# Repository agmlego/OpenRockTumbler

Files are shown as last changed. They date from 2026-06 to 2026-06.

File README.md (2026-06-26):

OpenRockTumbler
---------------

This project aims to be a drop-in replacement controller for common rock tumblers such as the KoolStone C1 Pro.

# Goals

* ESPHome-compatible controller for potential integration with Home Assistant
* Timer:
  * More than 9-day limit
  * Resume tumbling after power loss if time remaining
  * Periodic stir operation after timer end to prevent grit from settling
* Hall effect rotation sensor:
  * Detect if drum is actually turning
    * Alerts if belt breaks
  * Constant speed control

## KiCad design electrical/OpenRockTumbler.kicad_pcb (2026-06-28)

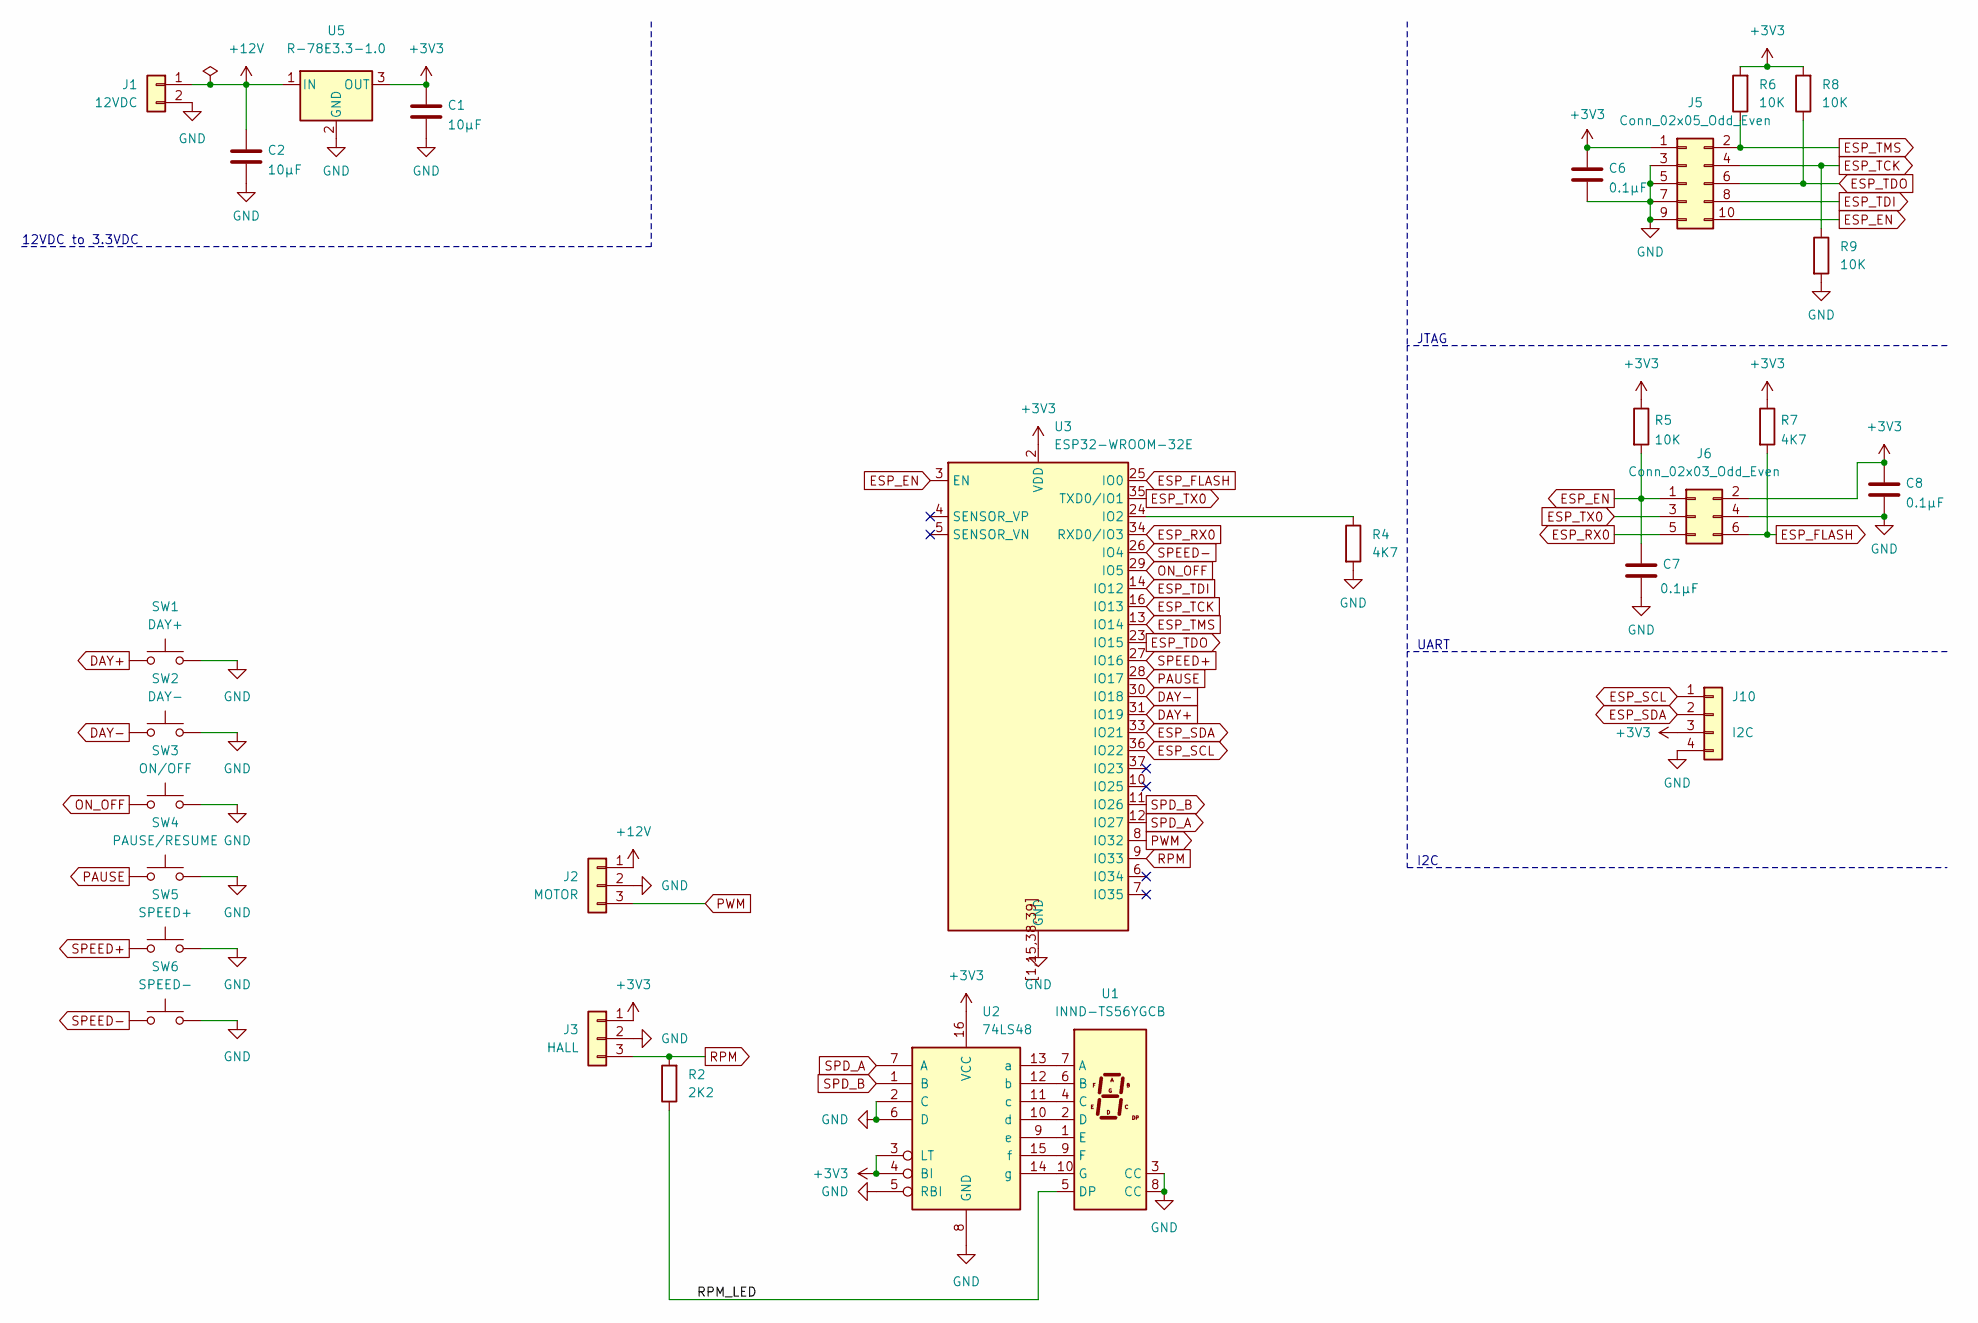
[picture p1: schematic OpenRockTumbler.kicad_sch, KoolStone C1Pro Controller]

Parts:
C1, C2: 10µF; CP_Elec_4x4.5
C6, C7, C8: 0.1µF; C_0603_1608Metric
J1: 12VDC; JST_PH_S2B-PH-K_1x02_P2.00mm_Horizontal
J2: MOTOR; JST_PH_S3B-PH-K_1x03_P2.00mm_Horizontal
J3: HALL; JST_PH_S3B-PH-K_1x03_P2.00mm_Horizontal
J5: Conn_02x05_Odd_Even; Tag-Connect_TC2050-IDC-NL_2x05_P1.27mm_Vertical
J6: Conn_02x03_Odd_Even; Tag-Connect_TC2030-IDC-NL_2x03_P1.27mm_Vertical
J10: I2C; JST_PH_S4B-PH-K_1x04_P2.00mm_Horizontal
R2: 2K2; R_0603_1608Metric
R4, R7: 4K7; R_0603_1608Metric
R5, R6, R8, R9: 10K; R_0603_1608Metric
SW1: DAY+; SW_PUSH_6mm
SW2: DAY-; SW_PUSH_6mm
SW3: ON/OFF; SW_PUSH_6mm
SW4: PAUSE/RESUME; SW_PUSH_6mm
SW5: SPEED+; SW_PUSH_6mm
SW6: SPEED-; SW_PUSH_6mm
U1: INND-TS56YGCB; D1X8K
U2: 74LS48; SOIC-16_3.9x9.9mm_P1.27mm
U3: ESP32-WROOM-32E
U5: R-78E3.3-1.0; Converter_DCDC_RECOM_R-78E-0.5_THT

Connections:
+3V3: C1.1, C6.1, C8.1, J3.1, J5.1, J6.2, J10.3, R5.1, R6.2, R7.1, R8.2, U2.3 (LT), U2.4 (BI), U2.16 (VCC), U3.2 (VDD), U5.3 (OUT)
+12V: C2.1, J1.1, J2.1, U5.1 (IN)
/RPM_LED: R2.1, U1.5 (DP)
DAY+: SW1.1, U3.31 (IO19)
DAY-: SW2.1, U3.30 (IO18)
ESP_EN: C7.1, J5.10, J6.1, R5.2, U3.3 (EN)
ESP_FLASH: J6.6, R7.2, U3.25 (IO0)
ESP_RX0: J6.5, U3.34 (RXD0/IO3)
ESP_SCL: J10.1, U3.36 (IO22)
ESP_SDA: J10.2, U3.33 (IO21)
ESP_TCK: J5.4, R9.1, U3.16 (IO13)
ESP_TDI: J5.8, U3.14 (IO12)
ESP_TDO: J5.6, R8.1, U3.23 (IO15)
ESP_TMS: J5.2, R6.1, U3.13 (IO14)
ESP_TX0: J6.3, U3.35 (TXD0/IO1)
GND: C1.2, C2.2, C6.2, C7.2, C8.2, J1.2, J2.2, J3.2, J5.3, J5.5, J5.7, J5.9, J6.4, J10.4, R4.2, R9.2, SW1.2, SW2.2, SW3.2, SW4.2, SW5.2, SW6.2, U1.3 (CC), U1.8 (CC), U2.2 (C), U2.5 (RBI), U2.6 (D), U2.8 (GND), U3.1 (GND), U3.15 (GND), U3.38 (GND), U3.39 (GND), U3.[1,15,38,39] (GND), U5.2 (GND)
unnamed: U1.7 (A), U2.13 (a)
unnamed: U1.6 (B), U2.12 (b)
unnamed: U1.4 (C), U2.11 (c)
unnamed: U1.2 (D), U2.10 (d)
unnamed: U1.1 (E), U2.9 (e)
unnamed: U1.9 (F), U2.15 (f)
unnamed: U1.10 (G), U2.14 (g)
unnamed: R4.1, U3.24 (IO2)
ON_OFF: SW3.1, U3.29 (IO5)
PAUSE: SW4.1, U3.28 (IO17)
PWM: J2.3, U3.8 (IO32)
RPM: J3.3, R2.2, U3.9 (IO33)
SPD_A: U2.7 (A), U3.12 (IO27)
SPD_B: U2.1 (B), U3.11 (IO26)
SPEED+: SW5.1, U3.27 (IO16)
SPEED-: SW6.1, U3.26 (IO4)

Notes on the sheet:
I2C
JTAG
UART
12VDC to 3.3VDC

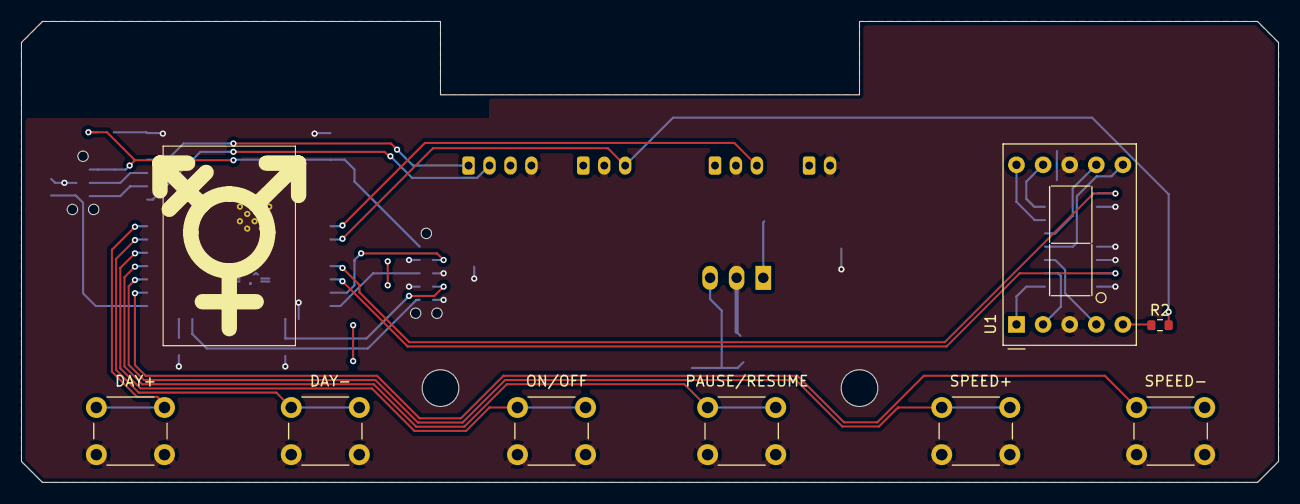
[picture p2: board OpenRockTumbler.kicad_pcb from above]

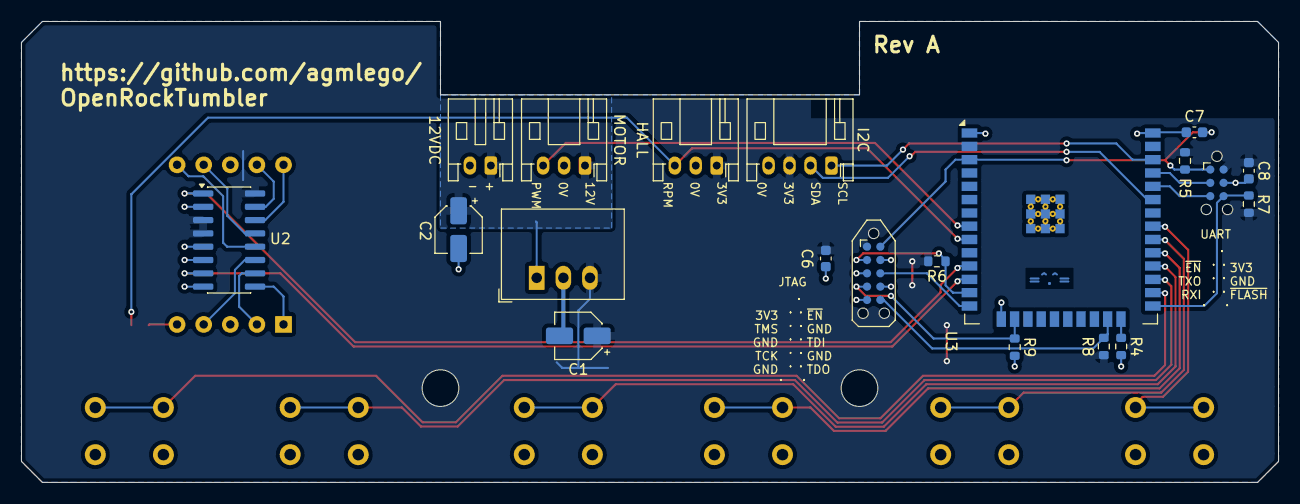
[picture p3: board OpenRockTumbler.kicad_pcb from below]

Board: 2 copper layers, 120.0 x 44.0 mm, 28 parts (20 on the bottom side), 32 nets.

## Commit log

2026-06-26 Initial commit with first pass routing on C1Pro board
    [OpenRockTumbler.kicad_pcb, OpenRockTumbler.kicad_sch]
2026-06-26 Update pcb_image.yaml for newer action API
2026-06-26 Updated silk
    [OpenRockTumbler.kicad_pcb, OpenRockTumbler.kicad_sch]
2026-06-26 Updated DRC for OSHPark
    [OpenRockTumbler.kicad_pcb]
2026-06-28 Replaced 5V regulator and 3V3 regulator with single 3V3 regulator
    [OpenRockTumbler.kicad_pcb, OpenRockTumbler.kicad_sch]
2026-06-30 Added sample screens as layers for the OLED screen
